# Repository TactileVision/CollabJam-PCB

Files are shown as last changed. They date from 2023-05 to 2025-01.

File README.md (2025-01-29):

# CollabJam: PCB

This repository contains KiCAD projects for the tactile display Printed Circuit Board (PCB).

CollabJam_v4_3D_2

## Repositories

Below are links to the individual repositories associated with the project:

- ⭐️ [Meta Repository](https://github.com/TactileVision/CollabJam) - The main repository.
- 🖥️ [Client App Repository](https://github.com/TactileVision/CollabJam-Client) - The main client application used for interacting with and designing vibrotactile experiences collaboratively.
- ⚙️ [Server Repository](https://github.com/TactileVision/CollabJam-Server) - The server application used for collaborative designing, shared rendering of vibrotactile patterns, and storing patterns in a database.
- ⚙️ [Share Components Repository](https://github.com/TactileVision/CollabJam-Shared) - Components which are shared across the server and client application.
- ⚙️ [Firmware Repository](https://github.com/TactileVision/CollabJam-Firmware) - Contains the firmware code for the tactile display used in the project.
- 📈 [Data Visualization Repository](https://github.com/TactileVision/CollabJam-Tacton-Table-Tool) - Tool for visualizing vibrotactile patterns collected during the study sessions.

## Citation

If you use this project in your research, please cite it as follows:

```bibtex
@inproceedings{Wittchen2025CollabJam,
    author = {Wittchen, Dennis and Ramian, Alexander and Sabnis, Nihar and Chlebowski, Christopher and Böhme, Richard and Freitag, Georg and Fruchard, Bruno and Degraen, Donald},
    title = {CollabJam: Studying Collaborative Haptic Experience Design for On-Body Vibrotactile Patterns},
    year = {2025},
    publisher = {Association for Computing Machinery},
    address = {New York, NY, USA},
    booktitle = {Proceedings of the 2025 CHI Conference on Human Factors in Computing Systems},
    location = {Yokohama, Japan},
    series = {CHI '25},
    doi = {10.1145/3706598.3713469}
}
```

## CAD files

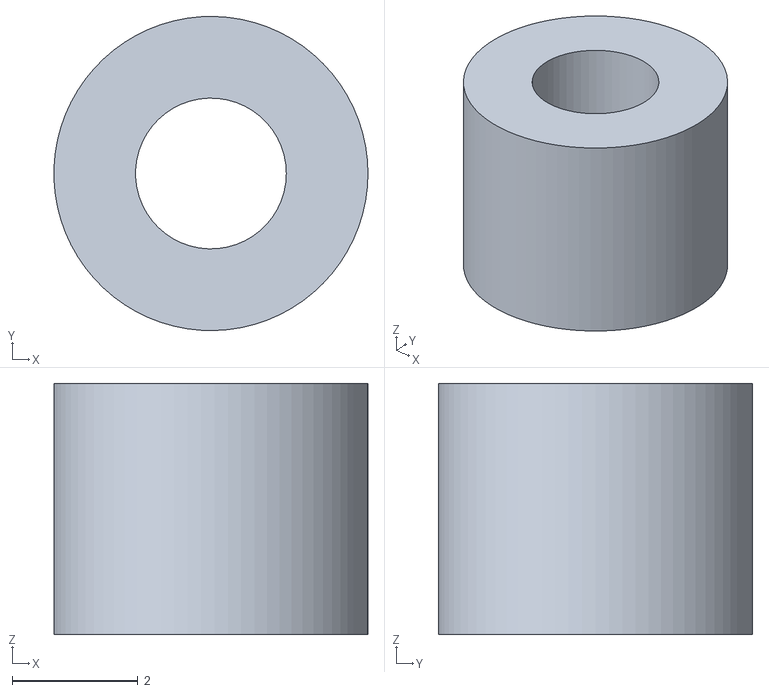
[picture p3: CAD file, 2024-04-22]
v4/case/CollabJam-case-spacer.stl
5.00 x 5.00 x 4.00

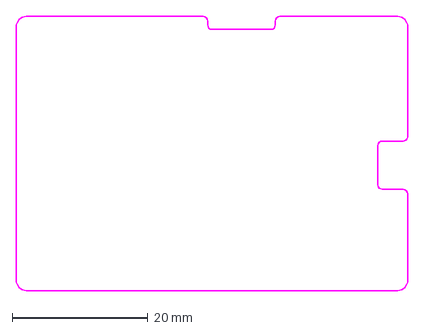
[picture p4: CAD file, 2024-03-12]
v4/edge_cut/edge_cut.dxf
57.6 x 40.4 mm

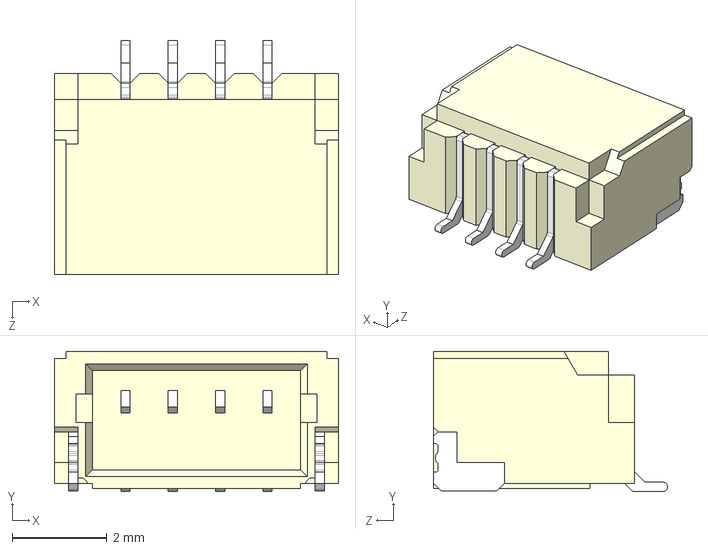
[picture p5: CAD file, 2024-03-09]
v4/project_libs/3d_models/SM04B-SRSS-TB--3DModel-STEP-269445.STEP
6.00 x 2.96 x 4.95 mm

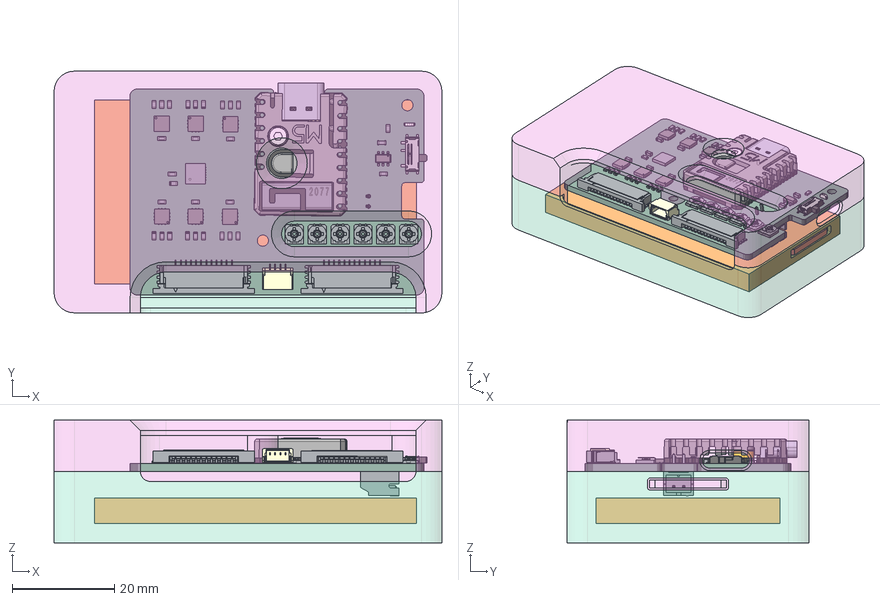
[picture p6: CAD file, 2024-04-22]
v4/case/CollabJam-case.FCStd
76.0 x 47.4 x 24.0 mm
TC-33X-1_ASM
TC-33X-1_ASM001
C_0603_1608Metric
R_0603_1608Metric
LTST-S220KFKT
LTST-S220KFKT001
LTST-S220KFKT002
LTST-S220KFKT003
TC-33X-1_ASM002
R_0603_1608Metric002
C_0603_1608Metric002
R_0603_1608Metric004
C_0603_1608Metric004
R_0603_1608Metric006
R_0603_1608Metric008
R_0603_1608Metric010
R_0603_1608Metric012
ASSEMBLY
ASSEMBLY001
ASSEMBLY002
ASSEMBLY003
ASSEMBLY004
ASSEMBLY005
ASSEMBLY006
ASSEMBLY007
ASSEMBLY008
ASSEMBLY009
ASSEMBLY010
ASSEMBLY011
ASSEMBLY012
TC-33X-1_ASM003
TC-33X-1_ASM004
R_0603_1608Metric014
JST_S2B_PH_K
R_0603_1608Metric016
ASSEMBLY014
ASSEMBLY015
ASSEMBLY016
ASSEMBLY017
ASSEMBLY018
ASSEMBLY019
ASSEMBLY020
ASSEMBLY022
ASSEMBLY023
ASSEMBLY024
ASSEMBLY025
ASSEMBLY026
ASSEMBLY027
ASSEMBLY028
ASSEMBLY029
ASSEMBLY030
ASSEMBLY031
ASSEMBLY032
ASSEMBLY033
ASSEMBLY034
Texas_RGE0024C_VQFN-24-1EP_4x4mm_P0.5mm_EP2.1x2.1mm
TC-33X-1_ASM005
C_0603_1608Metric006
ASSEMBLY036
ASSEMBLY037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

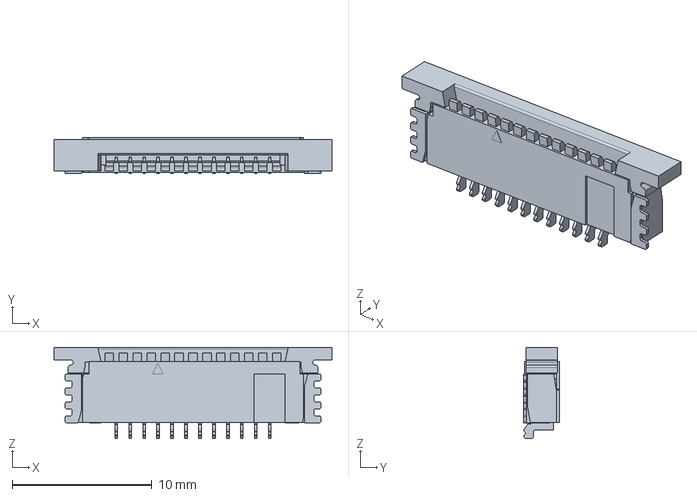
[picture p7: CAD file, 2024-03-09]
v4/project_libs/3d_models/1-84952-2.step
19.9 x 2.56 x 6.54 mm

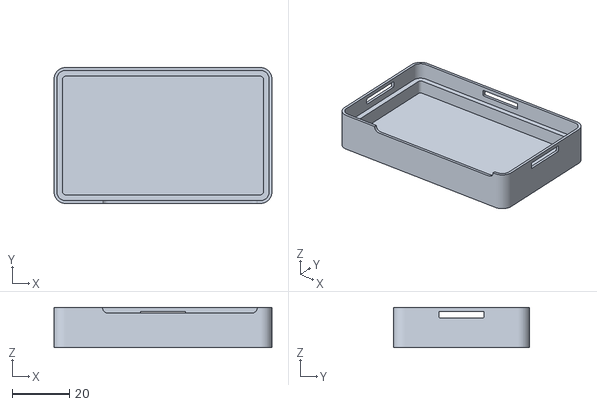
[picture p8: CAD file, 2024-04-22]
v4/case/CollabJam-case-bottom.stl
76.0 x 47.4 x 14.0

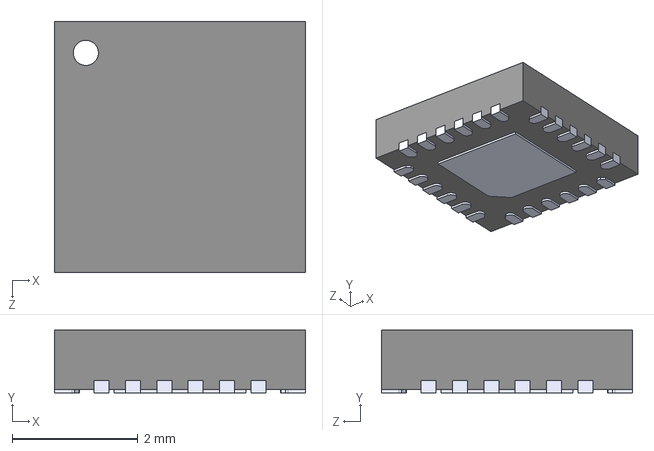
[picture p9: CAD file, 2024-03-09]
v4/project_libs/3d_models/TCA9548ARGER--3DModel-STEP-56544.STEP
4.00 x 1.00 x 4.00 mm

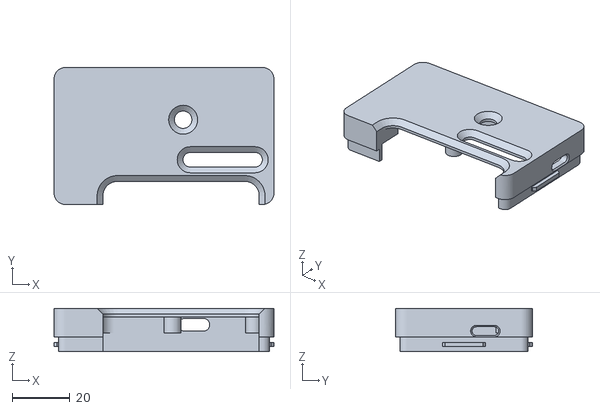
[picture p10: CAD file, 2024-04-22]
v4/case/CollabJam-case-top.stl
76.0 x 47.4 x 15.0

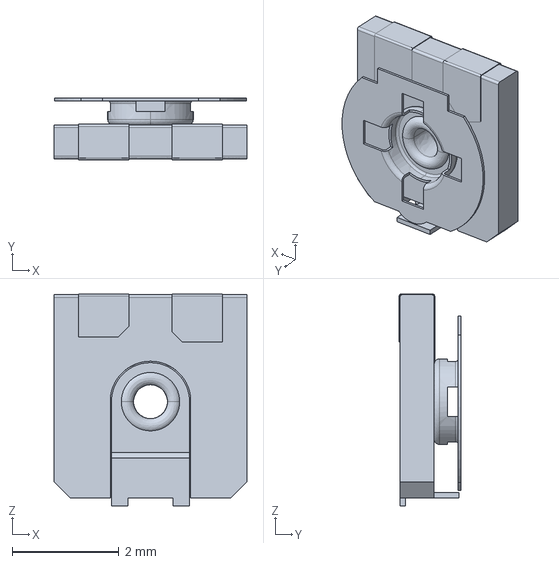
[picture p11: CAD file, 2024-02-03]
v4/project_libs/3d_models/TC-33X-2.stp
3.60 x 1.15 x 3.96 mm

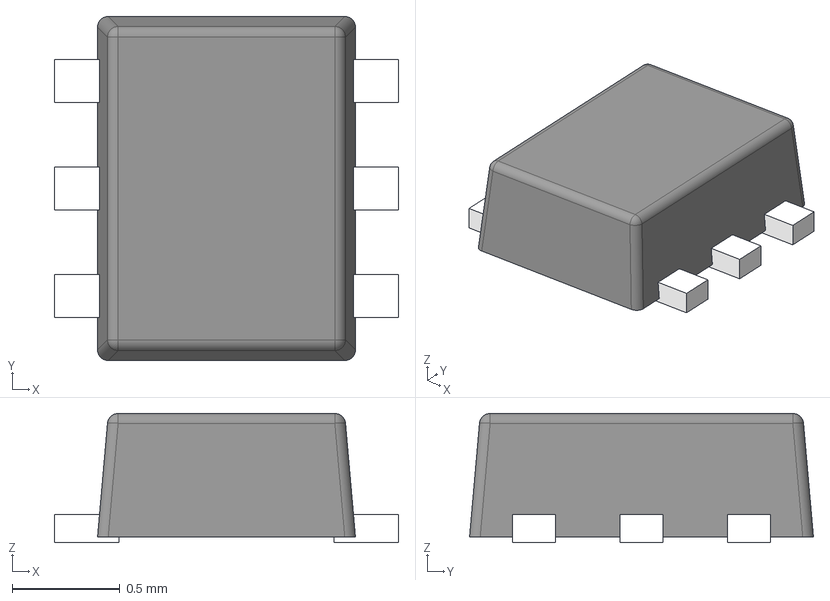
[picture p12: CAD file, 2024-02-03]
v4/project_libs/3d_models/DRL0006A.stp
1.60 x 1.60 x 0.6 mm
FRAME-DRL0006A
BODY-SOT
PIN1-ID

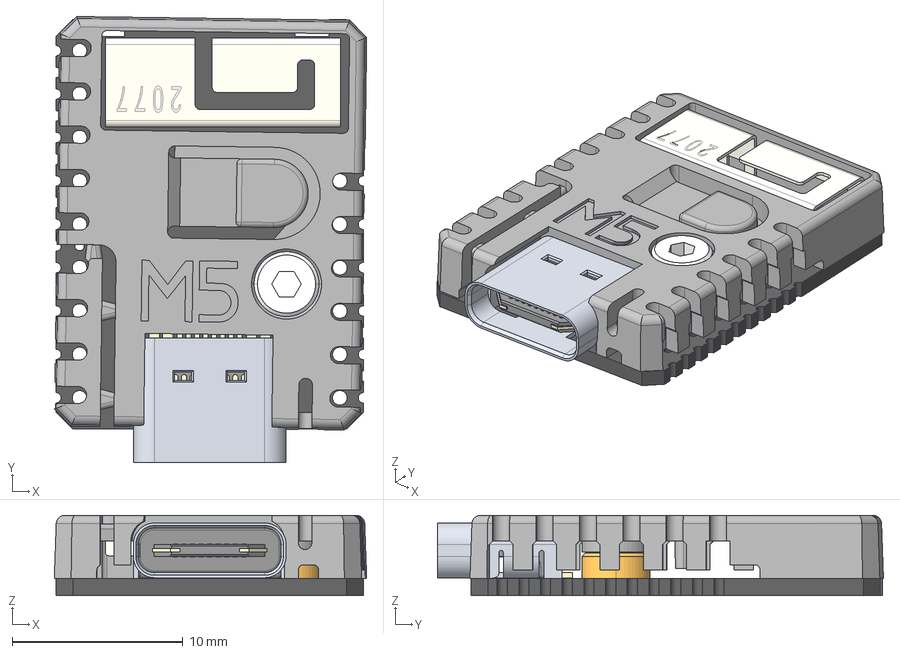
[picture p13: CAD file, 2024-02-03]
v4/project_libs/3d_models/M5STAMP-S3.step
18.3 x 26.1 x 4.70 mm
OPEN_CASCADE_STEP_TRANSLATO-247
M241_5MM_12_9MM00
R0402_ASM x 3
USB_TYPE_C_PORT__SMD_TYPE__1
USB_TYPE_C_PORT__SMD_TYPE__2
USB_TYPE_C_PORT__SMD_TYPE__3
USB_TYPE_C_PORT__SMD_TYPE__4
USB_TYPE_C_PORT__SMD_TYPE__5
USB_TYPE_C_PORT__SMD_TYPE__6
USB_TYPE_C_PORT__SMD_TYPE__7
USB_TYPE_C_PORT__SMD_TYPE__8
USB_TYPE_C_PORT__SMD_TYPE__9
USB_TYPE_C_PORT__SMD_TYPE__10
USB_TYPE_C_PORT__SMD_TYPE__11
USB_TYPE_C_PORT__SMD_TYPE__12
USB_TYPE_C_PORT__SMD_TYPE__13
USB_TYPE_C_PORT__SMD_TYPE__14
USB_TYPE_C_PORT__SMD_TYPE__15
USB_TYPE_C_PORT__SMD_TYPE__16
USB_TYPE_C_PORT__SMD_TYPE__17
USB_TYPE_C_PORT__SMD_TYPE__18
USB_TYPE_C_PORT__SMD_TYPE__19
USB_TYPE_C_PORT__SMD_TYPE__20
USB_TYPE_C_PORT__SMD_TYPE__21
USB_TYPE_C_PORT__SMD_TYPE__22
USB_TYPE_C_PORT__SMD_TYPE__23
USB_TYPE_C_PORT__SMD_TYPE__24
C0402_10UF_ASM
C0402_100NF_ASM x 2
C10_ASM
USER_LIBRARY-PRO-OB-440
STAMP-S3
CHS-M2X3

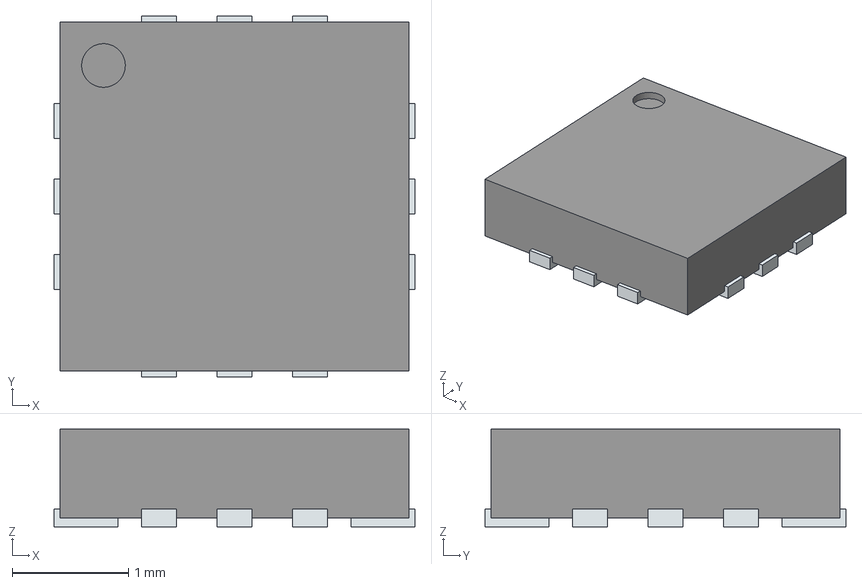
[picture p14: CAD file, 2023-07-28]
v4/project_libs/3d_models/DA7281-00FVC.stp
3.10 x 3.10 x 0.84 mm
PinsArrayLR
PinsArrayTB

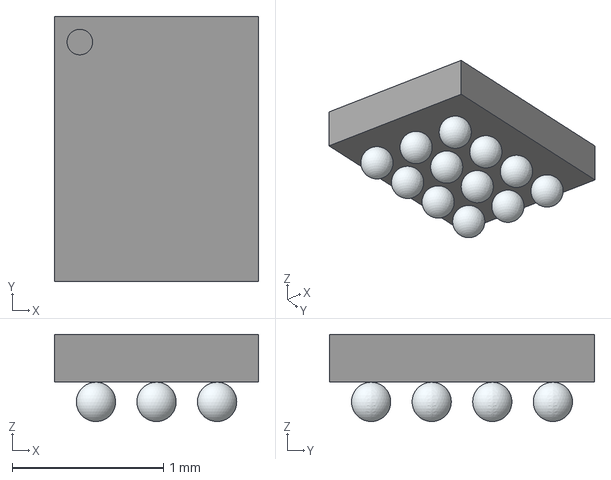
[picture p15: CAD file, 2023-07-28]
v4/project_libs/3d_models/DA7281-00V4C.stp
1.35 x 1.75 x 0.575 mm

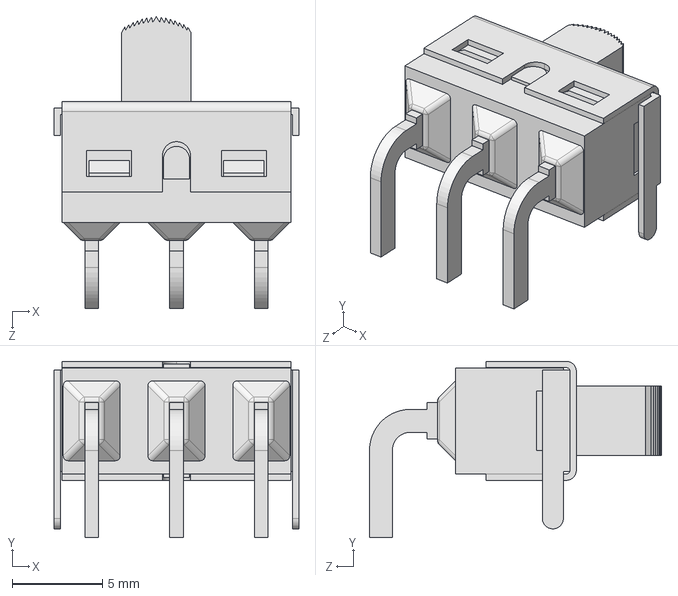
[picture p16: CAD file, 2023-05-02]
v4/project_libs/3d_models/500SSP1S1M6QEA.step
13.6 x 9.78 x 16.2 mm

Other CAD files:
v4/project_libs/3d_models/LTST-S220KFKT.stp
v4/project_libs/3d_models/SSAJ110100.stp
v4/project_libs/3d_models/SIP32510DT-T1-GE3.stp
v4/project_libs/3d_models/450404015514.stp
v1/case/case_v1.scad
v1/case/YAPPgenerator_v17.scad
v2/case/case_v2.scad
v2/case/YAPPgenerator_v17.scad
v1/CollabJam.stl
v1/case/case_v1.stl
v1/case/case_v1_bottom.stl
v1/case/case_v1_lid.stl
v2/case/case_v2.stl
v2/case/case_v2_bottom.stl
v2/case/case_v2_lid.stl
v3/edge_cut/edge_cut.dxf
v4/case/CollabJam-case.3mf
v4/project_libs/3d_models/L102021ML04Q.step

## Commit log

2023-05-02 add KiCAD project
    [500SSP1S1M6QEA.step, CollabJam.kicad_pcb, CollabJam.kicad_sch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]
2023-07-28 initial commit for v2.0
    [450404015514.stp, 500SSP1S1M6QEA.step, CollabJam.kicad_pcb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]
2023-07-28 switch to QFN package for DA7281
    [CollabJam.kicad_pcb, CollabJam.kicad_sch, CollabJam.stl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]
2023-08-02 start PCB layout
    [CollabJam.kicad_pcb, CollabJam.kicad_sch, motor_drivers-QFN.kicad_sch]
2023-08-06 first draft of the PCB
    [CollabJam.kicad_pcb, edge_cut.dxf]
2024-02-03 add project for v3
    [450404015514.stp, 500SSP1S1M6QEA.step, CollabJam.kicad_pcb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]
2024-02-03 first iteration ready for review
    [CollabJam.kicad_pcb, CollabJam.kicad_sch, TC-33X-2.stp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]
2024-02-06 add 5V power supply
    [CollabJam.kicad_pcb, CollabJam.kicad_sch]
2024-02-06 fix silkscreen
    [CollabJam.kicad_pcb]
2024-02-07 add keep-out zone for antenna
    [CollabJam.kicad_pcb]
2024-02-07 fix JST power supply connection
    [CollabJam.kicad_pcb, power_management.kicad_sch]
2024-02-07 fix series resistor for LED
    [CollabJam.kicad_pcb, power_management.kicad_sch]
2024-02-22 update schematic and board denominators
    [CollabJam.kicad_pcb, CollabJam.kicad_sch, analog_sensors.kicad_sch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]
2024-02-22 order pcb
    [CollabJam.kicad_pcb]
2024-03-09 v4 first draft
    [1-84952-2.step, 450404015514.stp, 500SSP1S1M6QEA.step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]
2024-03-10 board with edge cuts
    [CollabJam.kicad_pcb, edge_cut.dxf]
2024-03-11 v4 with edge cuts and passing drc
    [CollabJam.kicad_pcb, edge_cut.dxf]
2024-03-12 fix edge cut
    [CollabJam.kicad_pcb, edge_cut.dxf]
2024-03-13 add copper planes on top and bottom layer
    [CollabJam.kicad_pcb]
2024-03-27 fix bom
    [CollabJam.kicad_pcb, analog_sensors.kicad_sch, motor_drivers-QFN.kicad_sch]
2024-04-22 add case for PCB v4.1
    [CollabJam-case-bottom.stl, CollabJam-case-spacer.stl, CollabJam-case-top.stl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]
2024-04-23 feat: Added files for case of v1 and v2
    [YAPPgenerator_v17.scad, case_v1.scad, case_v1.stl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]
